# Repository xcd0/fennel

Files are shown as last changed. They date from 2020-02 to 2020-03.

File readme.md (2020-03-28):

# fennel

fan90のPCB、アクリルケースの発注が終わった。暇。この間に次のキーボードを作る。  
とりあえず名前はそのまま引き継ぐ。古いものは別ブランチに残す。別リポジトリにするかも...

## コンセプト

両手用左右分離型キーボード。fan90を小さくした。 片手に37キーの予定。  
ただしキーマトリクスが余る分を小さなリセットスイッチなどで設け、  
あまり使用頻度が高くない機能を割り当てる(マイコンの設定など)。  

* 指に合わせていい感じにキーが配置されてる両手で使えるキーボード欲しい。fan90二つはちょっと...
* fan90は流行に逆らったマキシマムな設計だったので、次は長いものに巻かれる小さ目な設計にする。
* 基盤はfan90と同じように両面対応する。
* fan90では筋力的にできなかった左右分割のキーボードにする。（左右間で通信する）
* ~~ケースはできれば3Dプリンターを使ってみる。~~ 基盤でケース作る方向にした。
* fan90のねじ数が少なくてちょっとたわむのでねじを増やす。
* Pro MicroではなくBluePillを使ってみる。

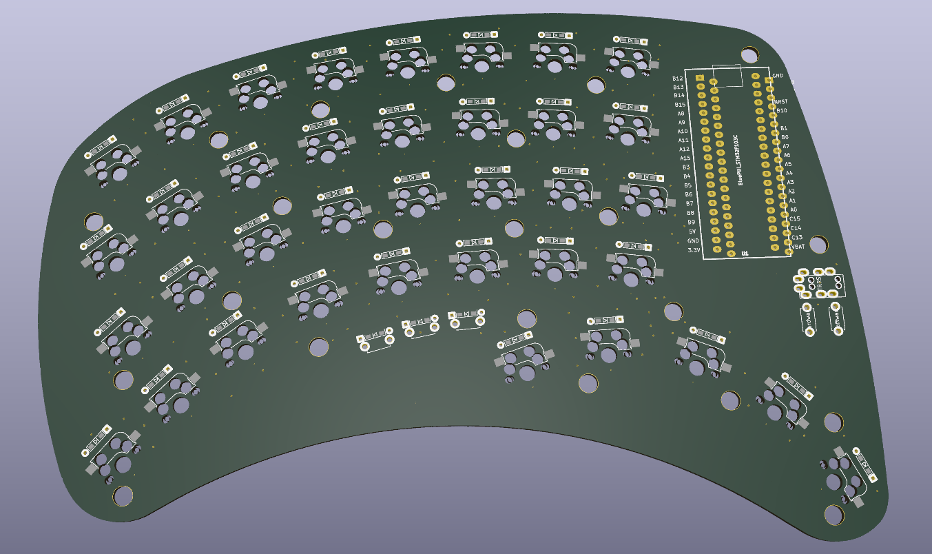
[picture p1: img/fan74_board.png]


外形が難しい... \_(:3 」∠ )\_

## 設計

fan90に比べ、
* 左右分離(通信)
* BluePillを使う(ARM)
の2点により難易度が上昇している。
というか参考にできる情報がすくない。

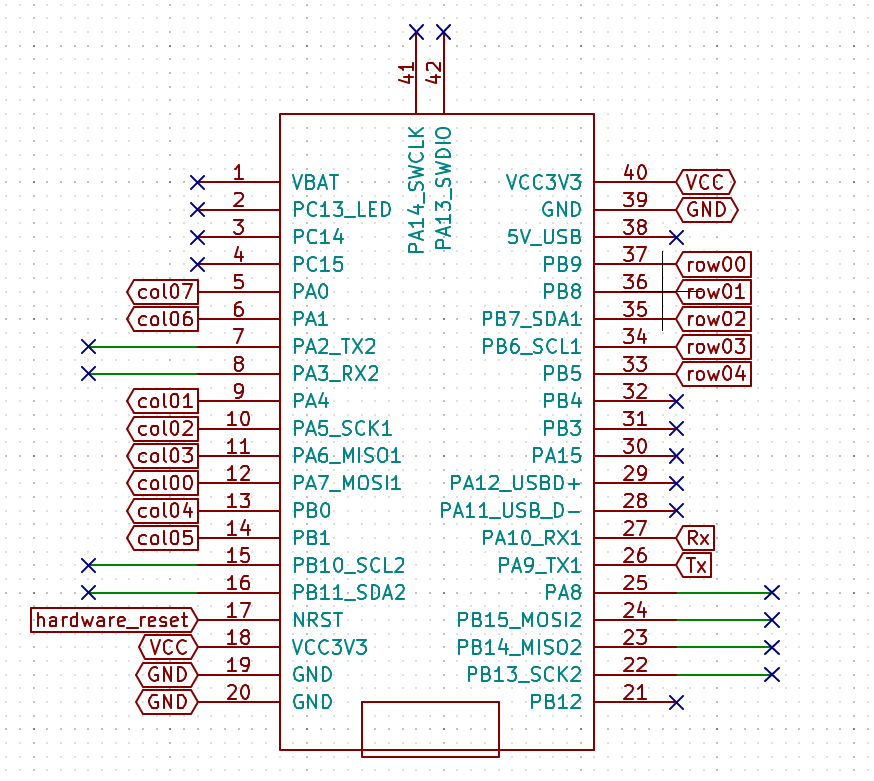
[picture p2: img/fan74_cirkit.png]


現状回路がよくなさそうなので長い目で決めていく。

* UART半二重通信をする予定
	* [](https://kondo-robot.com/faq/serial-servo-method-tech)
	* 右手のbluepillはスキャンしてひたすら左手に送信するだけ
	* 左手は受け取って左手のスキャン情報と合わせてPCにUSB経由で送信
	* 通信用の信号線(回路図のdata)はpullupしつつ、GNDとツェナーダイオードでつなぐ。
* pullup抵抗を入れる
	* 10kΩが多いみたい。
	* 1.5kΩの抵抗が余ってるからこれでもいいかな...
	* wikipediaによるとバイポーラは1kΩ～4.7kΩ、CMOSでは220kΩ～1MΩらしい
	* データシートにweak pull-up equivalent resistorの記述があるので、  
	内蔵のプルアップ抵抗も使えるみたい。VINとVSSをつなぐと30～50kΩになるみたい。(43ページ)
* RX は入力端子なので保護抵抗を入れる。
	* これも1.5kΩでいいかな...
	* データシートにたしかに10kΩ書いてあるので10kΩにした方がよさそう
* 使ってないIOピンもVCCかGNDに10kΩ挟んでつなぐ
	* どっちでもいいみたい
	* これは外部でプルアップ/ダウンする必要があるみたい
	> All unused pins must be held at a fixed voltage, by using the I/O output mode, an external pull-up or pull-down resistor
* キーマトリクスに割り当てるピン配置を変える

* 異種面付けをしてみた
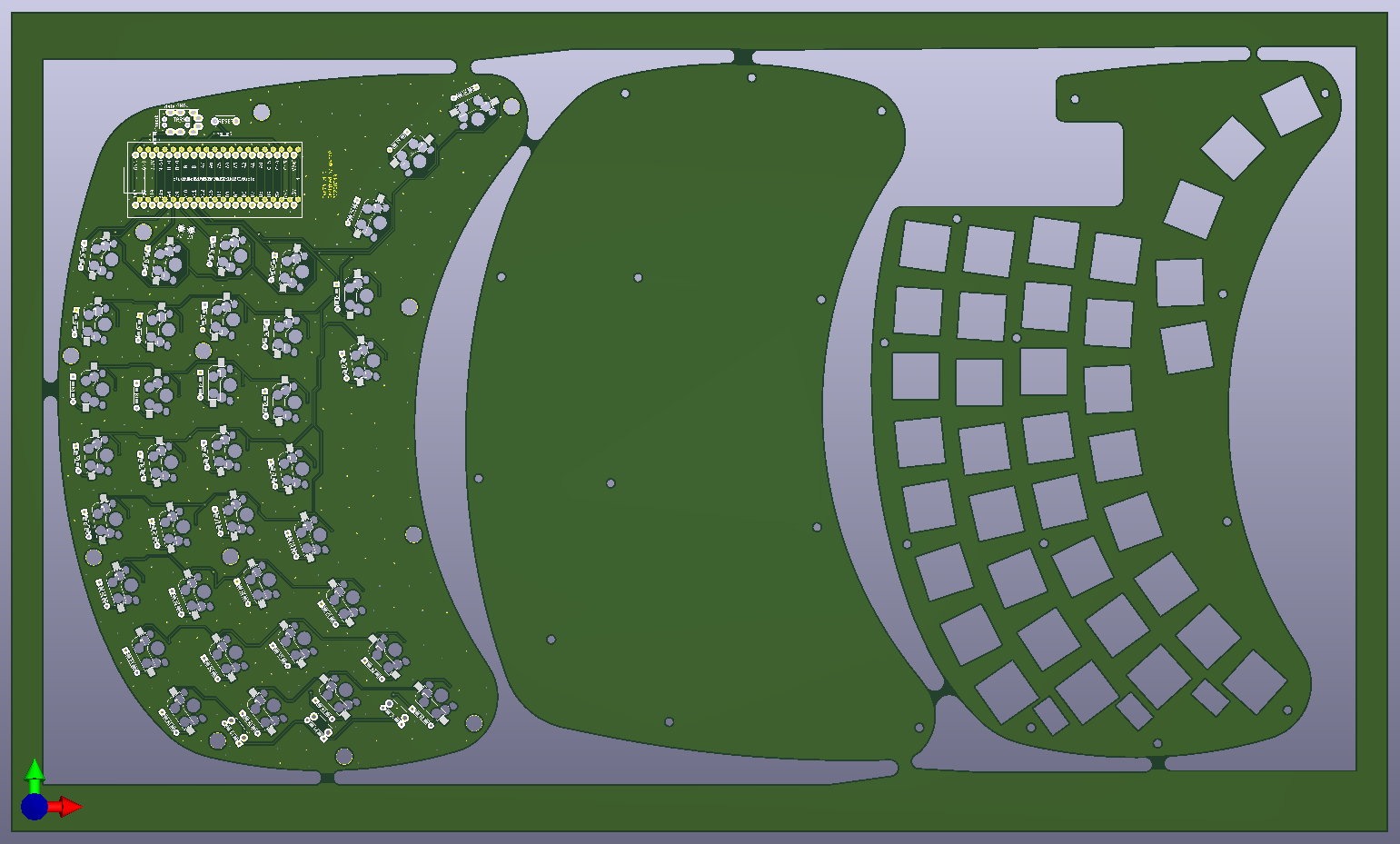
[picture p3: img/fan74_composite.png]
	
	* お値段 5枚製造
		* 異種面付けで基板製造の費用$93
		* 異種面付けしないで３枚頼んだ時の基板製造費$33
	* かすかに安いが、後加工が必要になるので、その点で普通に注文したほうよい。

### STM32F103について

調べて分かったことのメモ。間違っているかも。

* 内部回路の電源が分かれている。
	* VBAT はRTCとか用
		* ボタン電池とかをつないでRTCを維持できるみたい。
	* 1.8Vはコア回路用
	* VDDはデジタル回路用
	* VDDAはアナログ回路用

* リセットは3種類ある
	1. 電源を切る
	1. NRSTをGNDにつなぐ
	1. backup領域のみリセットする(そもそもbackup領域とは..)
		* BDRSTレジスタでリセット
		* VDDがONでリセット
		* VBATがONでリセット

* ピンについて
	* PA9がTx、PA10がRx。
	* PA15、PB3、PB4はJRAGデバッグに使われている(JTAGデバッグとは...)ので使おうとするとひと手間いる。
	* PB2はジャンパにつながっている。
	* PA11、PA12はUSB端子につながっている。
	* generic bootloader向け
		* bootloaderの種類はbluepillの実装に合わせる。generic_boot20_xxx.binのxxxはLEDのpinに合わせる。
			* 合わせることでDFUモードの状態をLEDで表示できる。
		* PA12はUSBリセットに使われているので、外部HWをつながない方がよい。
		* PC13はDFUの状態をLEDで表示するのに使われているので、外部HWをつながない方がよい。
		* PC14はNRSTに使われているので、外部HWをつながない方がよい。
			* PC14を3.3VにプルアップするとDFU永続モードになる？
			* DFU永続モードにできるなら有用なので専用回路を実装したい。
			* PC14をhigh→リセット→書き込み→PC14を開放→リセットの流れっぽい。

* 書き込みについて
	* USB経由での書き込みはタイミングよくリセットボタンを押す必要があるらしい。
		* 「Arduinoの書き込みを押した後0.5秒後くらいにボードのリセットを押す」らしい...

## リンク集

* 一番詳しかった  
ＤＥＫＯのアヤシいお部屋。 - STM32F103 https://ht-deko.com/arduino/stm32f103c8t6.html

* DFUモードの0.5秒の情報はここ  
adfmac/bluepill-arduino.md https://gist.github.com/tadfmac/f1dffc8c674ddaa8bd2340a8ddec65be

## ケース

基板と一緒に頼んだ。

## 回路間違っていた。
頼んだタイミングが残業で疲れた深夜だったため、いろいろミスった状態で発注した\_(:3 」∠ )\_
労働は体に良くない。

とりあえずゴリゴリ基盤を削って空中配線してごまかした。

## ファームウェア

[Ortho 75](https://github.com/qmk/qmk_firmware/tree/master/keyboards/cannonkeys/ortho75)を参考にする。

とりあえずこぴっていじる

<!--{{{-->

## 以下古いバージョン

<details>
<summary>v1 fan90 片手用フルキーボード</summary>

## one hand keyboard fan90

片手用キーボードです。G13のような用途を想定しています。  
左手で使うことを想定していますが、右手でも使えるようにPCBは作っています。  
流行りのミニマムなキーボードとは反対方向のマキシマムな方向のキーボードです。  
両手で使うことを想定していませんが、両面対応しているので2つ用意すれば可能です。  

初めての自作キーボードなので楽しみなのと不安なのが混在しています\_(:3 」∠ )\_
あくまで初めてつくる自作キーボードであるため、当然ながら動かない可能性が高いです。

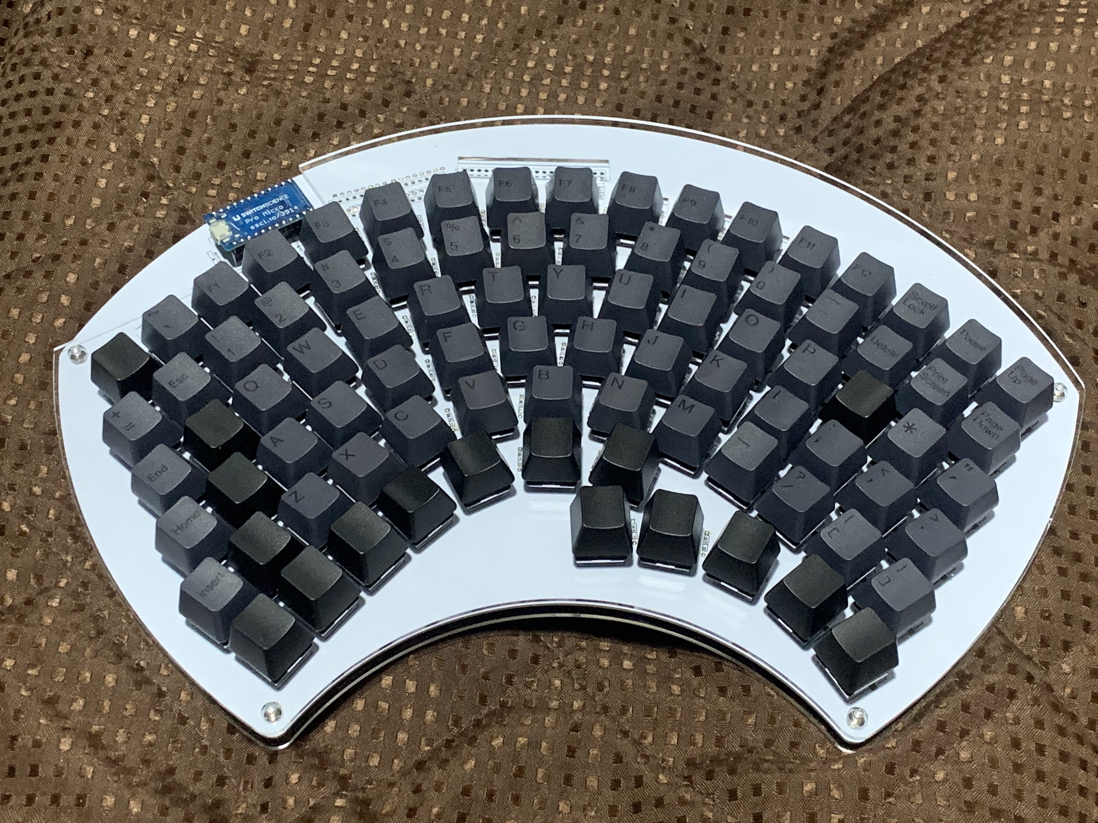
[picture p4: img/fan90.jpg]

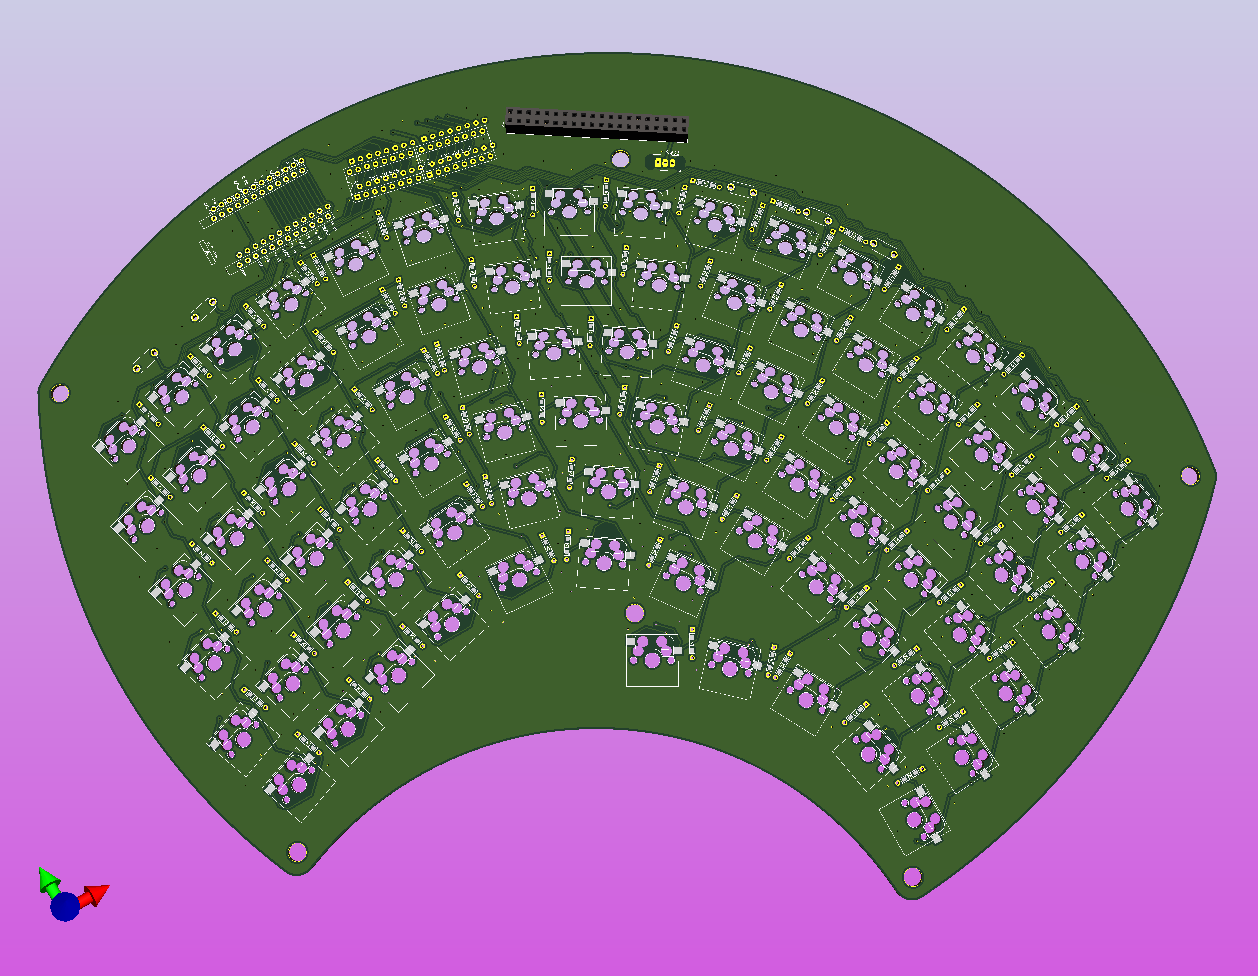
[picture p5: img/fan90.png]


<details>
<summary>開発経緯</summary>

### キーボード割ろうとしたら曲がった
* ありものは素晴らしい、でも自分で作ってみたい。よし、初めてのキーボード自作だ！PCBから作るぞ\\('ω')/
* 今使ってるhelixよい。でもErgodox的な縦のずれがあるキーボードもよさそう。そういうの作ろう...
* 左右分割型のキーボード良い。割りたい！でも左右の通信とかどうやってるんだろう...ちゃんと作れるかな...
* とりあえずキーを並べてみる。小指とか根元に近く配置しよう...
* 見た目汚いな...とりあえずきれいに並べてみるか...あれ、なんか曲がってきた...
* あれこれ片手でフルキーボードいけるんじゃ...

という感じでした\_(:3 」∠ )\_  
つまりキーボードを割ろうとしたが、  
筋力が足りなかったため（左右に分割したときの左右間の通信を電源(VCC,GND)と信号線の3本でどうやって通信してるのかわからなかったので）、  
割れずに曲がってしまった。  
次作るときは割りたい。  
名前は見た目がうちわのようになったため。  もちろん余った基板は重めの団扇として使うことができる。
鍋敷きにしてもよい。
</details>

<details>
<summary>構想</summary>

#### コンセプト
以下で東西南北を言うときは、左手で中指の方向を北とした場合の手のひらからの方向を指します。

* 片手でたくさんのキーを使える。
	* フルキーボード相当のキーを使えるものとする。
		* 現状6x15のマトリクスで87キーを配置。
		* 残り３キーはあまり使わない用途向けにリセットスイッチ部品で配置。

* 片手で使いやすい。
	* 指毎の特徴に合わせて配置する。  
		例えば
		* 親指はゲームのコントローラーで多用されるように本来非常に性能が良い。  
		しかしキーボードを使う上で親指を生かすのは難しい。  
		Twitterの投票によると親指に複数のキーを割り当てているときに使っているキーの数はせいぜい4キーらしい。  
		このキーボードでは多めに5キーを割り当てる。
		* 人差し指は性能が良くQWERTYでもほかの指より多いキーを担当する。  
		このキーボードでも人差し指の担当は多くする。
		* 中指は人差し指と同じくらいのせいのがある。中指にも多めのキーを割り当てる。
		* 薬指は中指と一緒に動かないと性能が良くないので、キーボードではあまり性能を発揮できない。
		ただし、北西方向は強く、北西方向に関しては小指より適している。。
		* 小指は短いので、北西方向の移動は難しい。  
		しかし西方向、南西方向はそこそこ性能が良い。
	* 指に合わせてキーを配置する。
		* 変則的な配置なので指１本に対して割り当てられたキーの数は様々。
			* 現状小指20、薬指15、中指12、人差し指31、親指5キー。人差し指と小指は無駄キーを含む。足しても90にはならない。
		* 将来的にはキーを立体的に配置するのもよいが、現状は平面に配置。
	* 指は伸ばした状態のほうが押しやすく、キーを押し分けやすい。
		* 指の根本に近いキーよりも指を伸ばしたときに押すキーのほうが押しやすい。
		* 指の根元に近いキーを減らし、指を伸ばしたときに押すキーを増やす。
	* レイヤーは極力つかわない。
		* シフトキーのように押しながら操作することは片手だと難しい。

* すべてのキーを常に使うキーにはせず、使う用途に合わせてカスタマイズできるよう、無駄にキーを配置する。

#### 実現方法

* 以下の2点からキーを扇状に配置する。
	* 小指の性能を発揮できるように小指のキーは手首側に寄せる。
	* 伸ばした状態で使える人差し指、中指のキーを増やす。
* 列方向には揃えず、行方向にはそろえる。
* 無駄にキーを小指の西側、人差し指の東側、すべての指の北側に配置する。つまり一回り大きくする。

#### 将来的にやりたいこと

* QMKを使わずに作る。(現状使う)
* C以外の言語で作る。(現状C言語)
* マイコンを複数種類使えるようにする。(現状むずかしい)
* raspberry pi zeroと画面を搭載して、それ単体でPCとして動作させ多機能にする。(現状ソケットのみ用意)
* ケースを3Dプリンターなどでつくる。
* キーを立体的に配置する。

</details>

### PCB設計

kicadを使って設計した。

回路は6x15のマトリクス。column方向からスキャンし、rowを検出する。  
column方向のスキャンは床に転がっていたSN74HC595を使う。  
シフトレジスタを使えば簡単にスキャンできそう。  
これで信号線数を15-5で10本減らせることになる。  
pro microはデジタルIOピンが14本、デジタルとしても使えるアナログIOピンが4本なので、
最大18本をデジタルIOとして使うことができる。
6本をrowのデジタル入力に、5本をシフトレジスタへのデジタル出力に、
2本をリセットスイッチに使用することにした。
配置は特にこだわりなく並べた。このせいで後々苦労するかもしれないがまあ初めてなので良しとする。

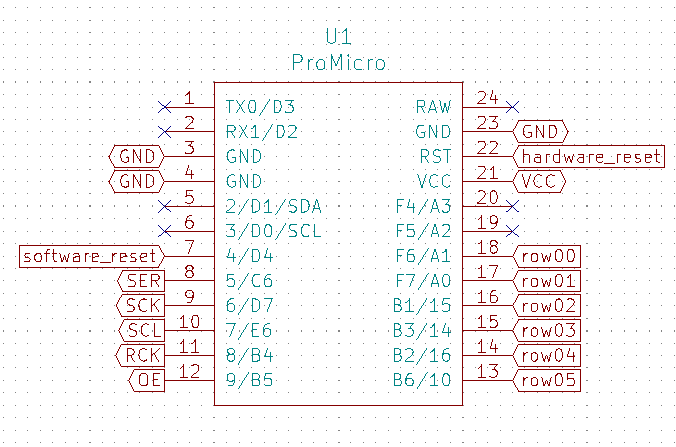
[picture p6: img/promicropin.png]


### アクリルケース設計

* ケースもとりあえずアクリルで作ることにした。
* ケースもDXFで入稿できるみたいなのでkicadでそのまま作った。
	* SVGでもよさそうだがそもそもSVGで線幅を狭くするとinkscapeやchromeで表示したとき線が描画されない問題があった。
* アクリルは[工房Emerge+](https://www.emergeplus.jp/laser-cutting-service/)を使ってみることにした。
	* elecrowはウェブサイトの調子が良くないのか、そもそもサービス中止中なのか、  
	https://twitter.com/xcd0/status/1233658167684296704  
	のようにfalseとなっていた。
	* 遊舎工房は、キーボードのサイズが大きいので元のアクリル板が最低でもA3より大きな必要があり、  
	A5,A4,450 X 300と、450x300以外の選択肢がなく、このサイズでも2枚発注する必要がある。  
	そして150x300程度の余白ができてしまう。
	* Emarge+は600x300に対応しており、これだと１枚に収まる。なのでここにしてみた。
	* 遊舎工房とEmerge+はillustratorありきの体制で、すごくストレスフルであった。
	* inkscapeは線幅の問題で使えず、外形と内形を色を変えるとかレイヤーを変えるとか言った操作はillustratorがないと難しいというか不可能な作業であった。
	* 今回５個ほどソフトを試したが、どれも満たせずあきらめてillustratorの7日間仕様版を使った。
	* 次回はaiやsvgではなくDXFで入稿したい。
	* elecrow復活してほしい...
* データ蹴られるかと思ったがとりあえず通った。
* DXFもレイヤー分けていればよいらしい。

### プログラム作成

qmkでもよいがとりあえず動作確認にarduinoを使う。
以下を参考にarduino studioで書き込めるか調べる。
https://learn.sparkfun.com/tutorials/pro-micro--fio-v3-hookup-guide#installing-windows
https://learn.sparkfun.com/tutorials/pro-micro--fio-v3-hookup-guide/hardware-overview-pro-micro



</details>
<!--}}}-->

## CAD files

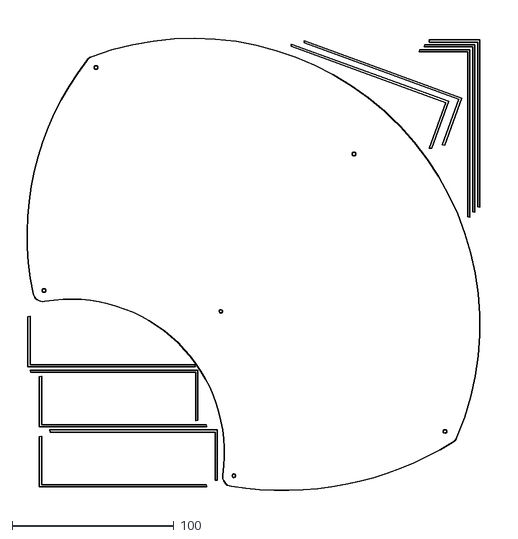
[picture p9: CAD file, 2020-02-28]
fan/fan_case/fan_case-Eco2_User.dxf
300.2 x 298.2

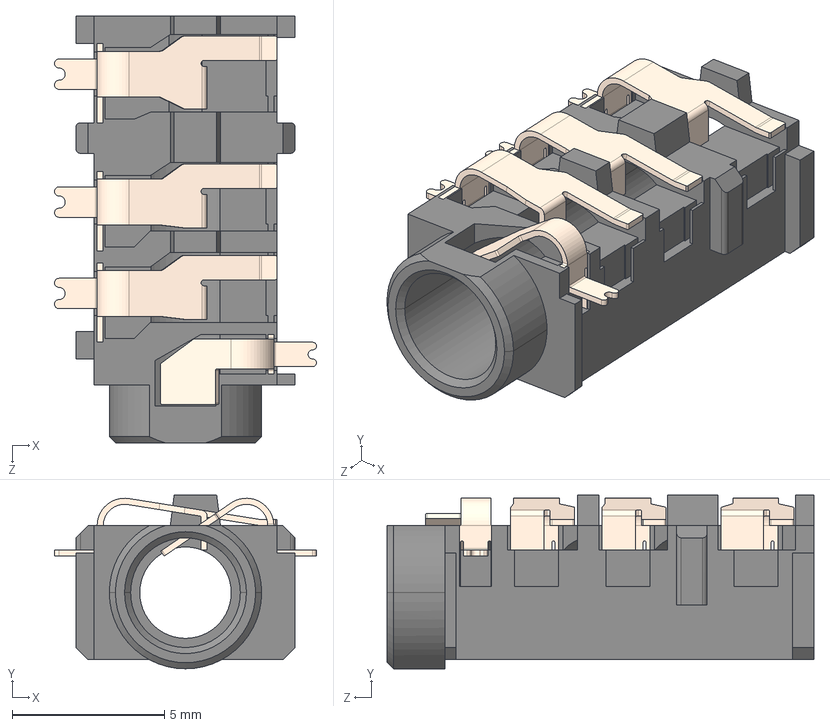
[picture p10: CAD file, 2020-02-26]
kbd/Keebio-Parts.pretty-master/3dmodels/CUI_SJ-43614-SMT-TR.step
8.60 x 5.70 x 14.0 mm

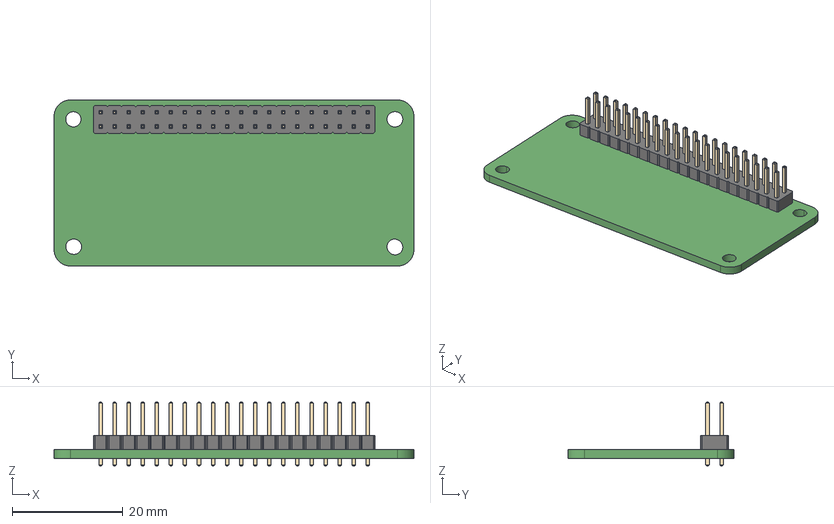
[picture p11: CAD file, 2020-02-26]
kbd/KiCad-Templates-master/3D Models/Raspberry Pi Zero W.step
65.0 x 30.0 x 11.5 mm

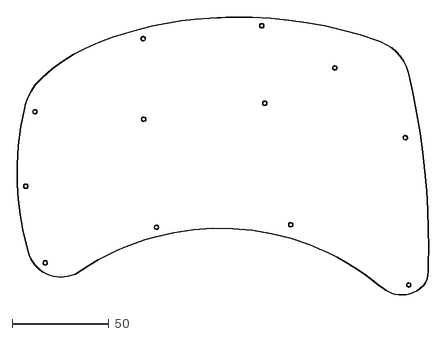
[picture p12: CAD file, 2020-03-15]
pcb/gbr/fan-Eco2_User.dxf
213.3 x 144.8

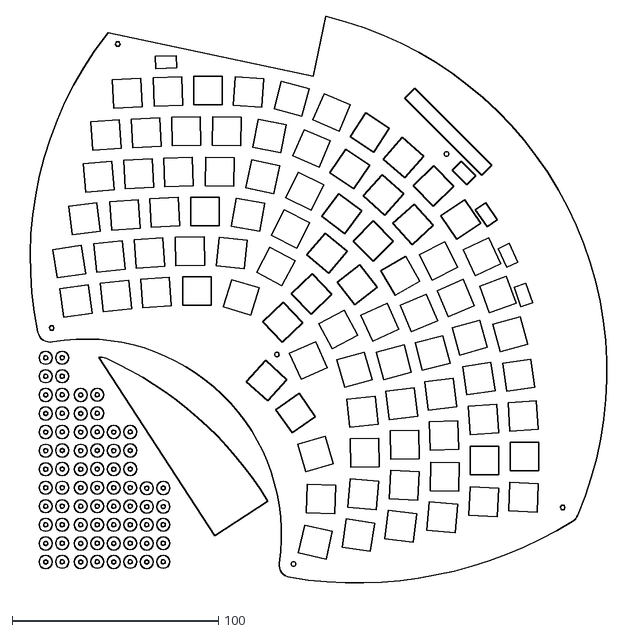
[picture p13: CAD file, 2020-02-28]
fan/fan_case/fan_case-Eco1_User.dxf
292.9 x 279.8

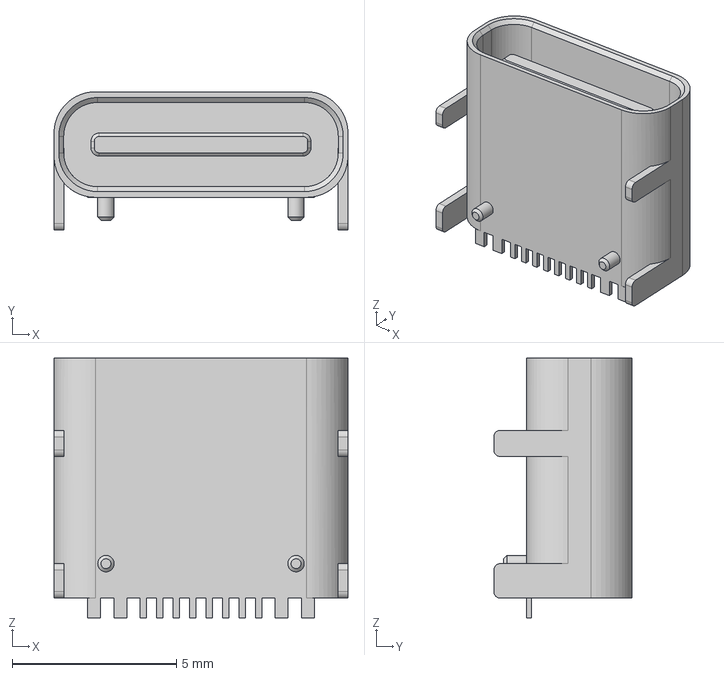
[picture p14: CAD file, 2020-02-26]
kbd/Keebio-Parts.pretty-master/3dmodels/HRO TYPE-C-31-M-12.step
8.94 x 4.21 x 7.90 mm

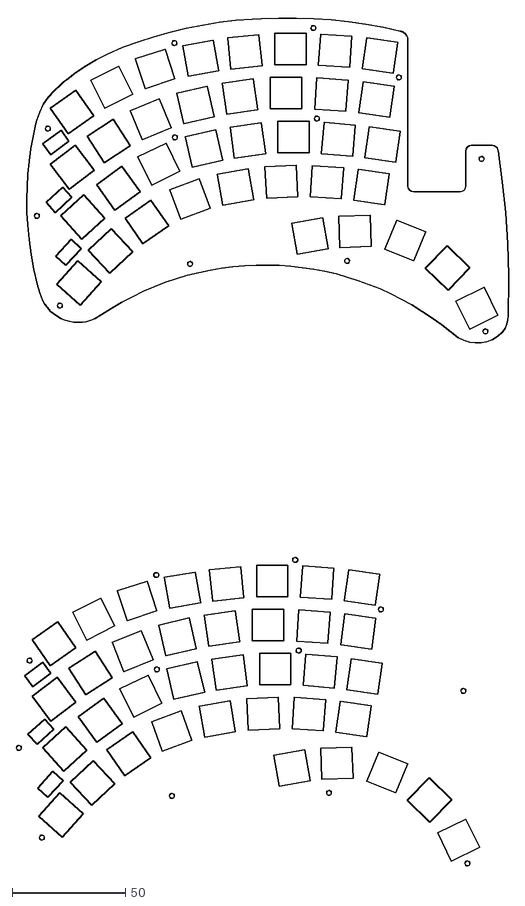
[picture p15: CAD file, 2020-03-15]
pcb/gbr/fan-Eco1_User.dxf
217.5 x 375.4

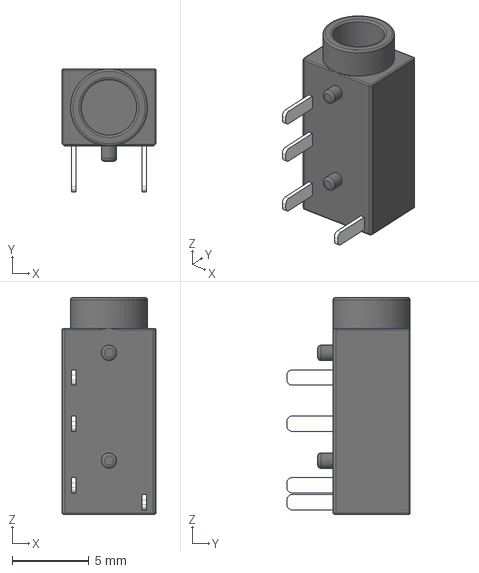
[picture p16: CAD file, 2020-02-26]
kbd/Keebio-Parts.pretty-master/3dmodels/PJ-320A.step
6.10 x 8.00 x 14.1 mm

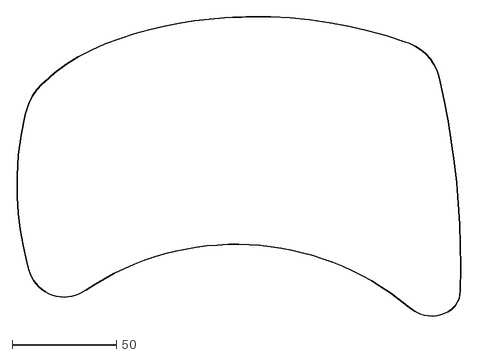
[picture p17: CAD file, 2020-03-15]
pcb/gbr/fan-Edge_Cuts.dxf
213.3 x 144.8

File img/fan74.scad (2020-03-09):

translate([0, 0, 4]) 
linear_extrude(height=1.6){
  offset(0){
    union(){
import("./pcb/gbr/fan-Edge_Cuts.dxf", $fa=1);
    }
  }
};
translate([0, 0, 0]) 
linear_extrude(height=2){
  offset(1){
    union(){
import("./pcb/gbr/fan-Edge_Cuts.dxf", $fa=1);
    }
  }
};

translate([0, 0, 5.6]) 
linear_extrude(height=2){
    
  difference(){
  offset(3){
import("./pcb/gbr/fan-Edge_Cuts.dxf", $fa=1);
}
import("./pcb/gbr/fan-Eco1_User.dxf", $fa=1);
  }
};

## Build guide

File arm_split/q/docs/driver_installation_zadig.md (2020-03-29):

# Bootloader Driver Installation with Zadig

QMK presents itself to the host as a regular HID keyboard device, and as such requires no special drivers. However, in order to flash your keyboard on Windows, the bootloader device that appears when you reset the board often *does*.

There are two notable exceptions: the Caterina bootloader, usually seen on Pro Micros, and the HalfKay bootloader shipped with PJRC Teensys, appear as a serial port and a generic HID device respectively, and so do not require a driver.

We recommend the use of the [Zadig](https://zadig.akeo.ie/) utility. If you have set up the development environment with MSYS2 or WSL, the `qmk_install.sh` script will have asked if you want it to install the drivers for you.

## Installation

Put your keyboard into bootloader mode, either by hitting the `RESET` keycode (which may be on a different layer), or by pressing the reset switch that's usually located on the underside of the board. If your keyboard has neither, try holding Escape or Space+`B` as you plug it in (see the [Bootmagic](feature_bootmagic.md) docs for more details). Some boards use [Command](feature_command.md) instead of Bootmagic; in this case, you can enter bootloader mode by hitting Left Shift+Right Shift+`B` or Left Shift+Right Shift+Escape at any point while the keyboard is plugged in.
Some keyboards may have specific instructions for entering the bootloader. For example, the [Bootmagic Lite](feature_bootmagic.md#bootmagic-lite) key (default: Escape) might be on a different key, e.g. Left Control; or the magic combination for Command (default: Left Shift+Right Shift) might require you to hold something else, e.g. Left Control+Right Control. Refer to the board's README file if you are unsure.

To put a device in bootloader mode with USBaspLoader, tap the `RESET` button while holding down the `BOOT` button.
Alternatively, hold `BOOT` while inserting the USB cable.

Zadig will automatically detect the bootloader device. You may sometimes need to check **Options → List All Devices**.

 - For keyboards with Atmel AVR MCUs, the bootloader will be named something similar to `ATm32U4DFU`, and have a Vendor ID of `03EB`.
 - USBasp bootloaders will appear as `USBasp`, with a VID/PID of `16C0:05DC`.
 - AVR keyboards flashed with the QMK-DFU bootloader will be named `<keyboard name> Bootloader` and will also have the VID `03EB`.
 - For most ARM keyboards, it will be called `STM32 BOOTLOADER`, and have a VID/PID of `0483:DF11`.

!> If Zadig lists one or more devices with the `HidUsb` driver, your keyboard is probably not in bootloader mode. The arrow will be colored orange and you will be asked to confirm modifying a system driver. **Do not** proceed if this is the case!

If the arrow appears green, select the driver, and click **Install Driver**. The `libusb-win32` driver will usually work for AVR, and `WinUSB` for ARM, but if you still cannot flash the board, try installing a different driver from the list. For flashing a USBaspLoader device via command line with msys2, the `libusbk` driver is recommended, otherwise `libusb-win32` will work fine if you are using QMK Toolbox for flashing.

Zadig with a bootloader driver correctly installed

Finally, unplug and replug the keyboard to make sure the new driver has been loaded. If you are using the QMK Toolbox to flash, exit and restart it too, as it can sometimes fail to recognize the driver change.

## Recovering from Installation to Wrong Device

If you find that you can no longer type with the keyboard, you may have accidentally replaced the driver for the keyboard itself instead of for the bootloader. This can happen when the keyboard is not in the bootloader mode. You can easily confirm this in Zadig - a healthy keyboard has the `HidUsb` driver installed on all of its interfaces:

A healthy keyboard as seen by Zadig

Open the Device Manager and look for a device that looks like your keyboard.

The board with the wrong driver installed, in Device Manager

Right-click it and hit **Uninstall device**. Make sure to tick **Delete the driver software for this device** first.

The Device Uninstall dialog, with the "delete driver" checkbox ticked

Click **Action → Scan for hardware changes**. At this point, you should be able to type again. Double check in Zadig that the keyboard device(s) are using the `HidUsb` driver. If so, you're all done, and your board should be functional again!

?> A full reboot of your computer may sometimes be necessary at this point, to get Windows to pick up the new driver.

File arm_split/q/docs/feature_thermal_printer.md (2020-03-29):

# Thermal Printer

<!-- FIXME: Describe thermal printers support here. -->

## Thermal Printer Keycodes

|Key |Description |
|---|---|
|`PRINT_ON` |Start printing everything the user types|
|`PRINT_OFF`|Stop printing everything the user types |

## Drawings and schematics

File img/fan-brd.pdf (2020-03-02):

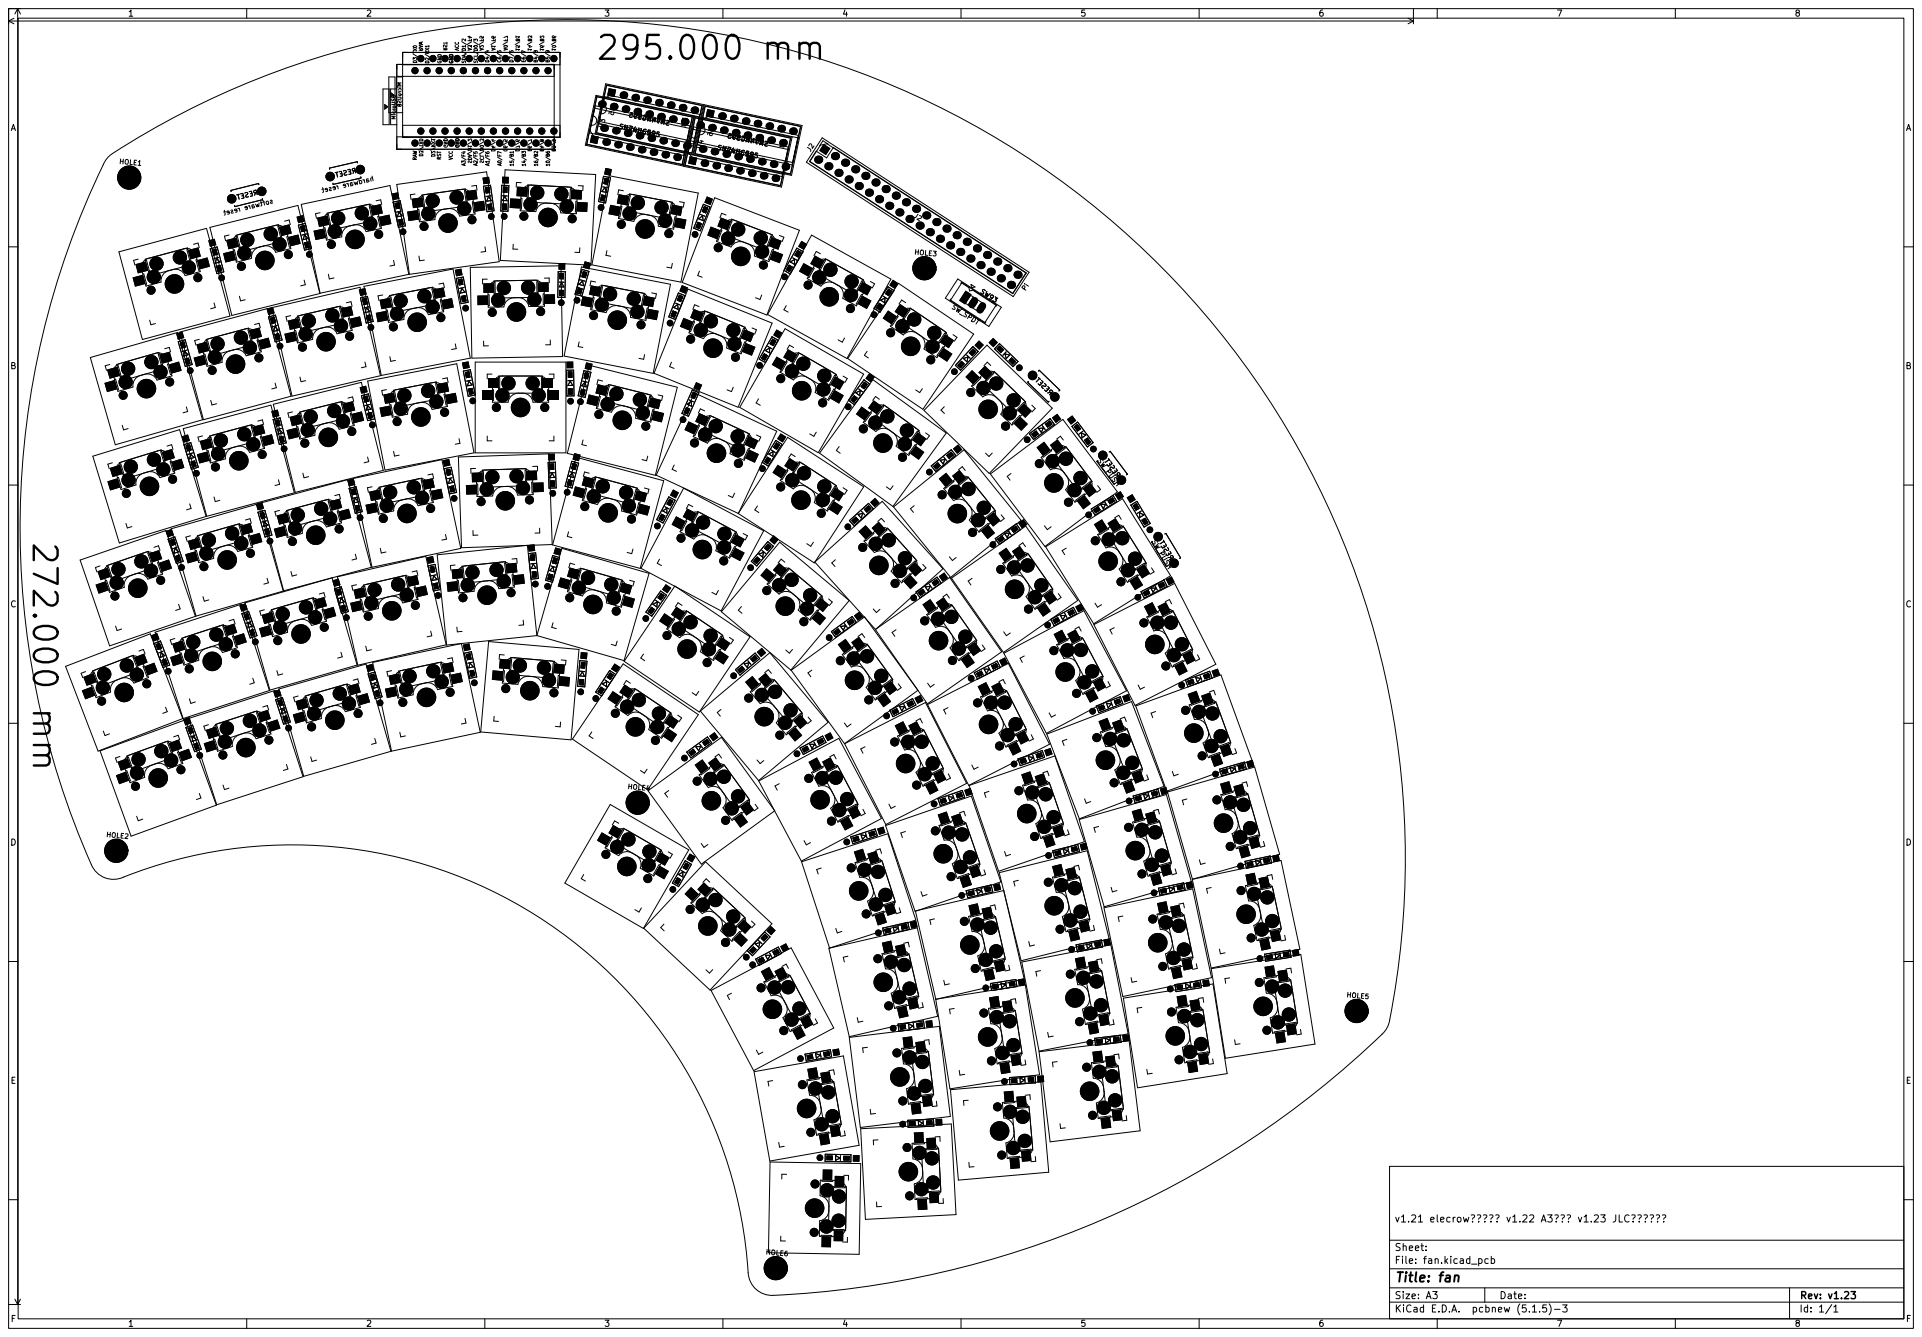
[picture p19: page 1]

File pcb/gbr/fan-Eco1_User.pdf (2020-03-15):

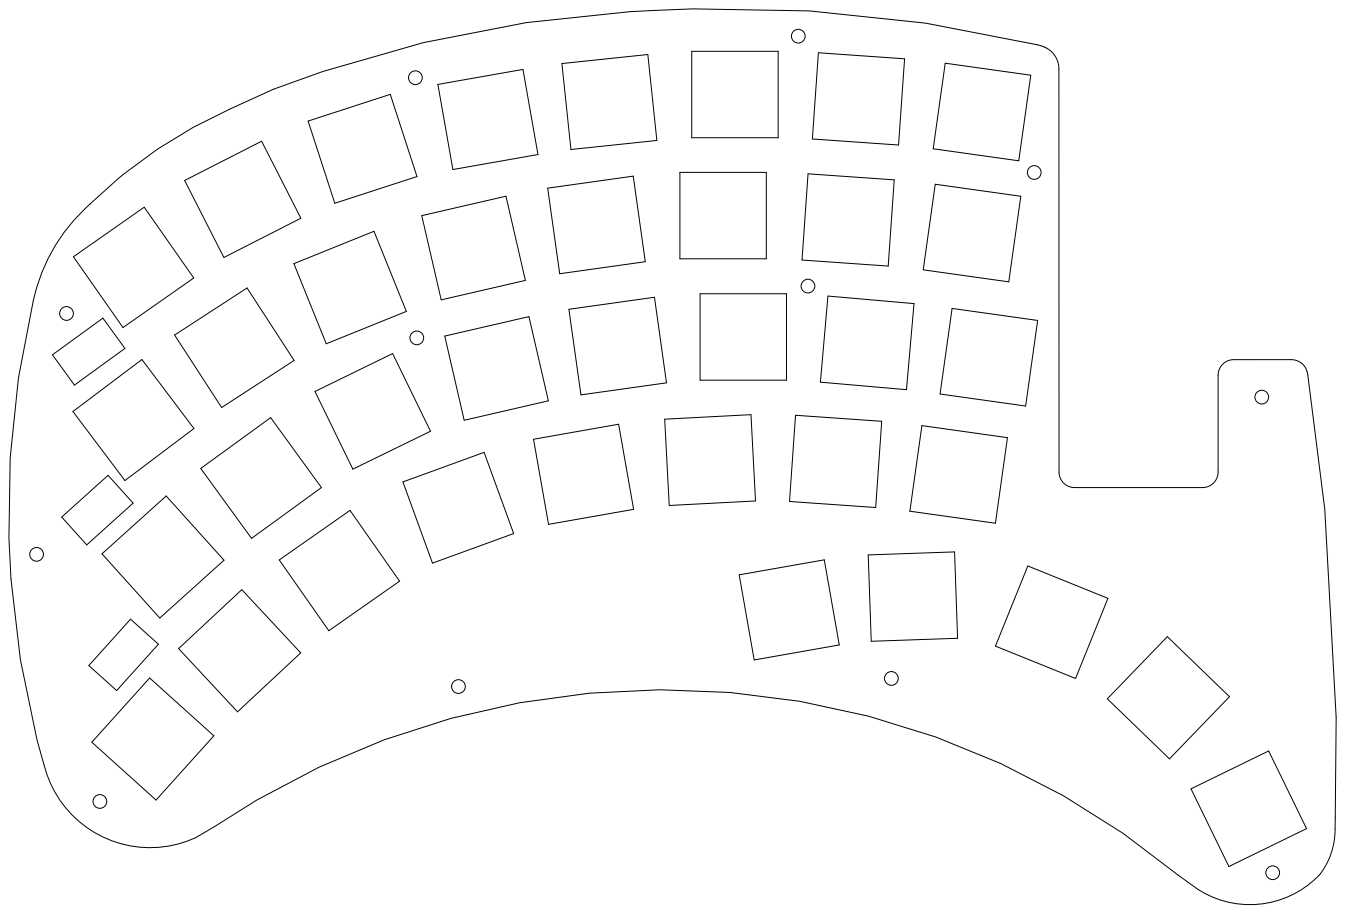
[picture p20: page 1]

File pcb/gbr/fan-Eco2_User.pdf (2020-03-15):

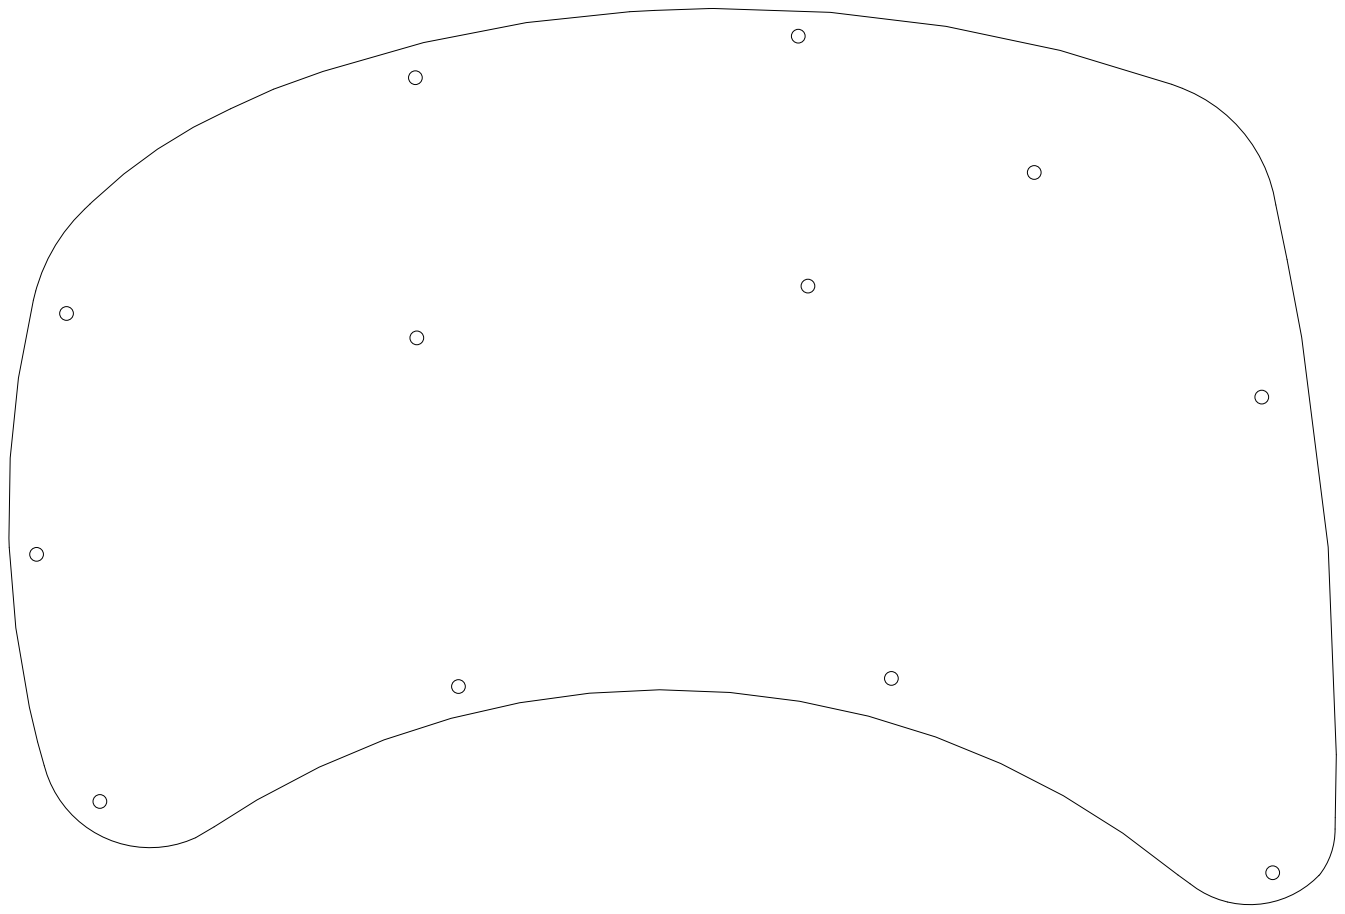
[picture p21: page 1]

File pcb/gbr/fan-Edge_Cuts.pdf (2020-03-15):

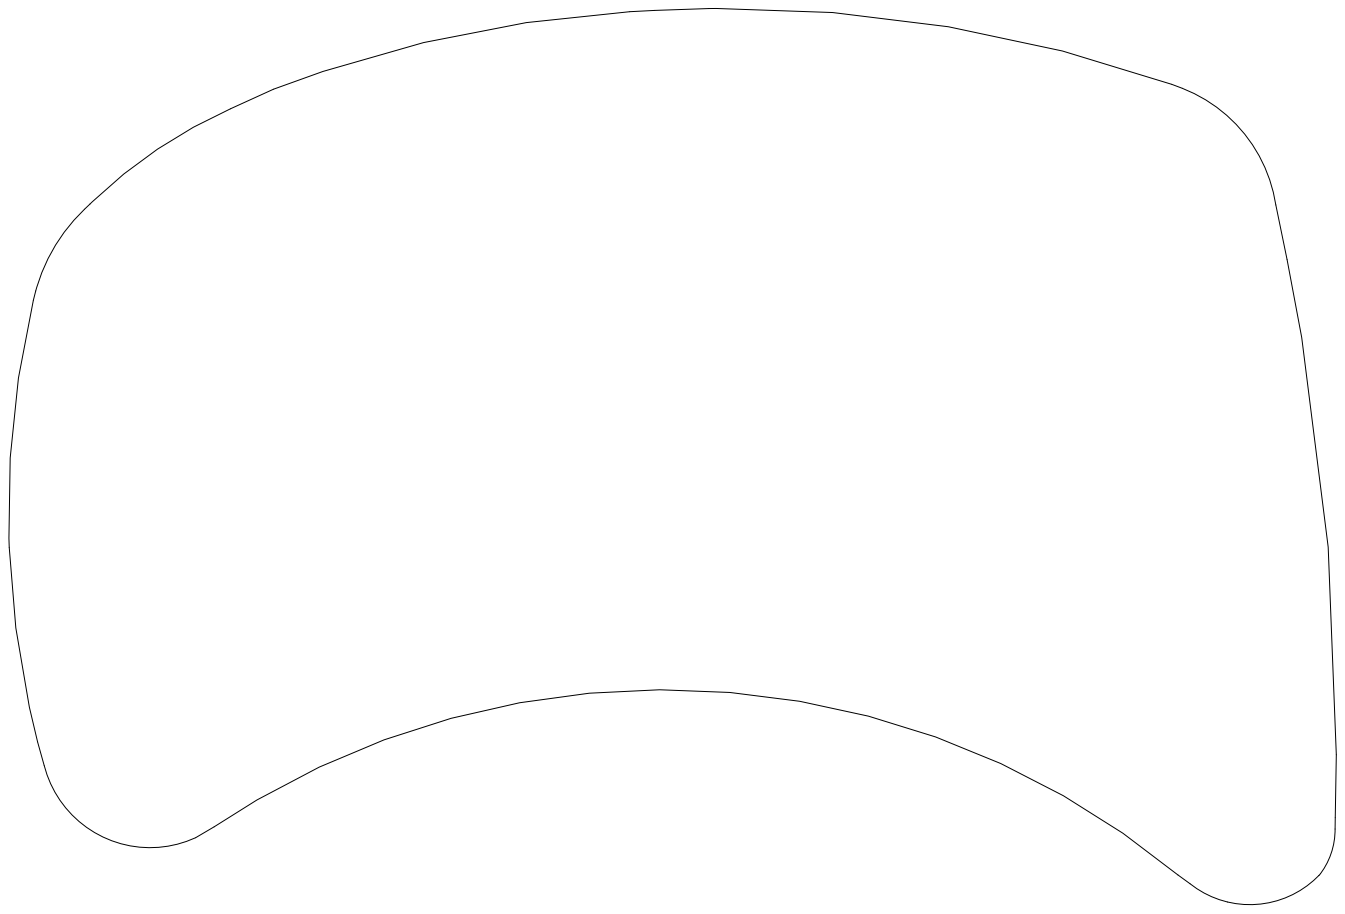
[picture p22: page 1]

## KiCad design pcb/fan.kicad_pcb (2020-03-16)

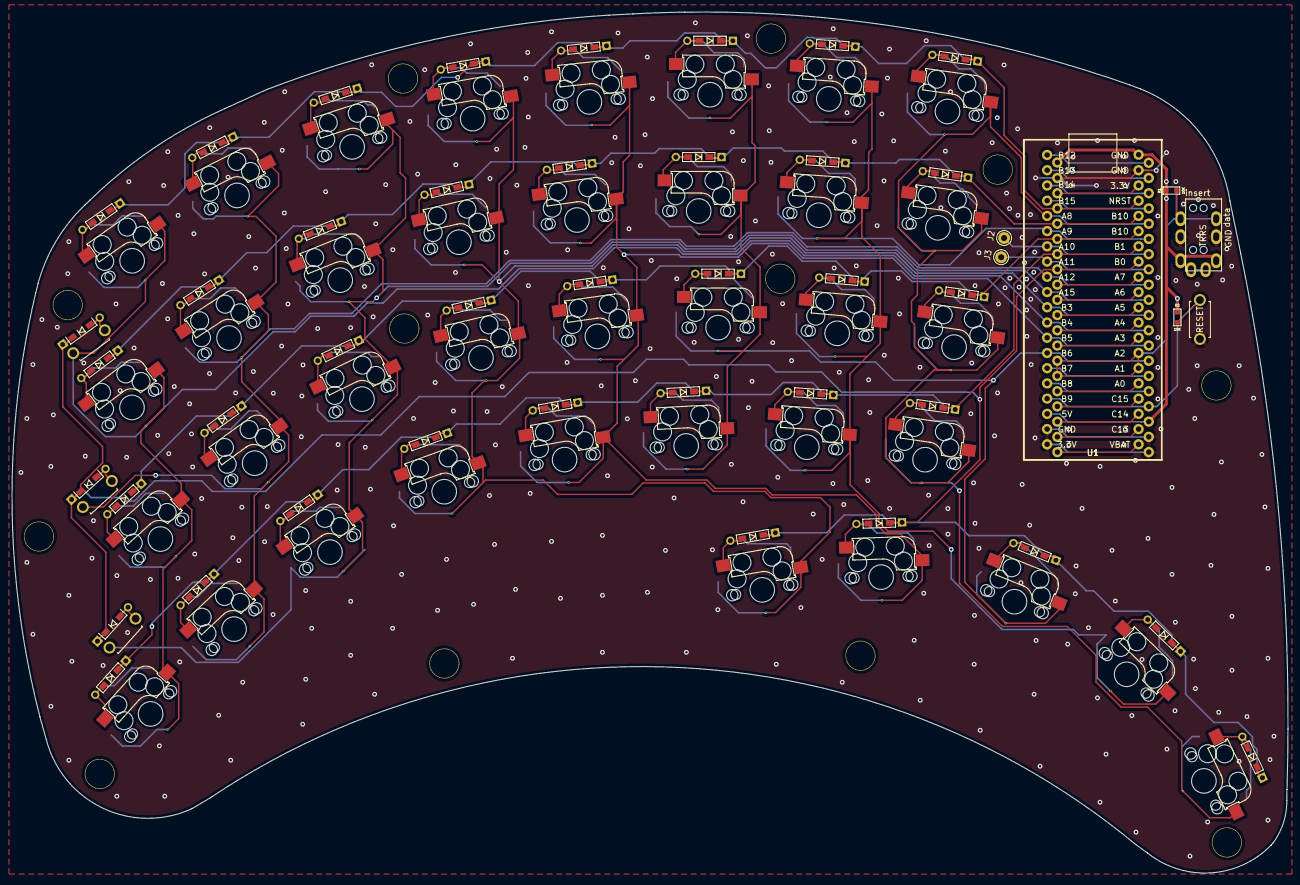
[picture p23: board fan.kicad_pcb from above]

Board: 2 copper layers, 212.8 x 143.6 mm, 59 parts (0 on the bottom side), 19 nets.

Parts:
J1: MJ-4PP-9
J2, J3: Conn_01x01_Female; Pin_D1.0mm_L10.0mm
R1, R2: 10K; R_1608_rev2
Ref**: Val**; HOLE
Ref**#2, Ref**#3, Ref**#4, Ref**#5, Ref**#6, Ref**#7, Ref**#8, Ref**#9, Ref**#10, Ref**#11, Ref**#12: Val**; HOLE
SW1, SW2, SW3, SW4, SW6, SW7, SW8, SW9, SW11, SW12, SW13, SW14, SW16, SW17, SW18, SW19, SW20, SW21, SW22, SW23, SW24, SW25, SW26, SW27, SW28, SW29, SW30, SW31, SW32, SW33, SW34, SW35, SW36, SW37, SW38, SW39, SW40: SW_PUSH-kbd; CherryMX_MidHeight_Hotswap_edit
SW5, SW10, SW15: SW_PUSH-kbd; ResetSW_with_diode
SW41: SW_PUSH; ResetSW
U1: BluePill_STM32F103C; BluePill_STM32F103C_0.9_Double

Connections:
GND: J1.C, SW41.2, U1.19, U1.20, U1.39
unnamed: J2.1, U1.7
unnamed: J3.1, U1.8
Rx: J1.B, R1.2, U1.26, U1.27
VCC: J1.D, R1.1, R2.1, U1.18, U1.40
col00: SW1.1, SW2.1, SW3.1, SW4.1, SW5.1, U1.12
col01: SW6.1, SW7.1, SW8.1, SW9.1, SW10.1, U1.9
col02: SW11.1, SW12.1, SW13.1, SW14.1, SW15.1, U1.10
col03: SW16.1, SW17.1, SW18.1, SW19.1, SW20.1, U1.11
col04: SW21.1, SW22.1, SW23.1, SW24.1, SW25.1, U1.13
col05: SW26.1, SW27.1, SW28.1, SW29.1, SW30.1, U1.14
col06: SW31.1, SW32.1, SW33.1, SW34.1, SW35.1, U1.6
col07: SW36.1, SW37.1, SW38.1, SW39.1, SW40.1, U1.5
hardware_reset: R2.2, SW41.1, U1.17
row00: SW1.3, SW6.3, SW11.3, SW16.3, SW21.3, SW26.3, SW31.3, SW36.3, U1.37
row01: SW2.3, SW7.3, SW12.3, SW17.3, SW22.3, SW27.3, SW32.3, SW37.3, U1.36
row02: SW3.3, SW8.3, SW13.3, SW18.3, SW23.3, SW28.3, SW33.3, SW38.3, U1.35
row03: SW4.3, SW9.3, SW14.3, SW19.3, SW24.3, SW29.3, SW34.3, SW39.3, U1.34
row04: SW5.3, SW10.3, SW15.3, SW20.3, SW25.3, SW30.3, SW35.3, SW40.3, U1.33

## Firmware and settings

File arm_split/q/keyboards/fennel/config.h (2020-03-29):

/*
Copyright 2020 xcd0

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
You should have received a copy of the GNU General Public License
along with this program.  If not, see <http://www.gnu.org/licenses/>.
*/

#pragma once

//#include "config_common.h"

/* USB Device descriptor parameter */
#define VENDOR_ID 0xFEED
#define PRODUCT_ID 0x0000
#define DEVICE_VER 0x0001
#define MANUFACTURER xcd0
#define PRODUCT fennel
#define DESCRIPTION A custom keyboard

/* key matrix size */
#define MATRIX_ROWS 5
#define MATRIX_COLS 16 // 片手で8 両手で16

#define MATRIX_ROW_PINS { B9, B8, B7, B6, B5  }
#define MATRIX_COL_PINS { A7, A4, A5, A6, B0, B1, A1, A0 }
#define UNUSED_PINS { B10, B11, B13, B14, B15, A8 }

/* COL2ROW, ROW2COL*/
#define DIODE_DIRECTION COL2ROW
//#define DIODE_DIRECTION CUSTOM_MATRIX

/*
 * Split Keyboard specific options, make sure you have 'SPLIT_KEYBOARD = yes' in your rules.mk, and define SOFT_SERIAL_PIN.
 */
//#define SOFT_SERIAL_PIN D0  // or D1, D2, D3, E6

// #define BACKLIGHT_PIN B7
// #define BACKLIGHT_BREATHING
// #define BACKLIGHT_LEVELS 3

// #define RGB_DI_PIN E2
// #ifdef RGB_DI_PIN
//   #define RGBLED_NUM 16
//   #define RGBLIGHT_HUE_STEP 8
//   #define RGBLIGHT_SAT_STEP 8
//   #define RGBLIGHT_VAL_STEP 8
//   #define RGBLIGHT_LIMIT_VAL 255 /* The maximum brightness level */
//   #define RGBLIGHT_SLEEP  /* If defined, the RGB lighting will be switched off when the host goes to sleep */
// /*== all animations enable ==*/
//   #define RGBLIGHT_ANIMATIONS
// /*== or choose animations ==*/
//   #define RGBLIGHT_EFFECT_BREATHING
//   #define RGBLIGHT_EFFECT_RAINBOW_MOOD
//   #define RGBLIGHT_EFFECT_RAINBOW_SWIRL
//   #define RGBLIGHT_EFFECT_SNAKE
//   #define RGBLIGHT_EFFECT_KNIGHT
//   #define RGBLIGHT_EFFECT_CHRISTMAS
//   #define RGBLIGHT_EFFECT_STATIC_GRADIENT
//   #define RGBLIGHT_EFFECT_RGB_TEST
//   #define RGBLIGHT_EFFECT_ALTERNATING
// /*== customize breathing effect ==*/
//   /*==== (DEFAULT) use fixed table instead of exp() and sin() ====*/
//   #define RGBLIGHT_BREATHE_TABLE_SIZE 256      // 256(default) or 128 or 64
//   /*==== use exp() and sin() ====*/
//   #define RGBLIGHT_EFFECT_BREATHE_CENTER 1.85  // 1 to 2.7
//   #define RGBLIGHT_EFFECT_BREATHE_MAX    255   // 0 to 255
// #endif

/* Debounce reduces chatter (unintended double-presses) - set 0 if debouncing is not needed */
#define DEBOUNCE 5

/* define if matrix has ghost (lacks anti-ghosting diodes) */
//#define MATRIX_HAS_GHOST

/* Mechanical locking support. Use KC_LCAP, KC_LNUM or KC_LSCR instead in keymap */
#define LOCKING_SUPPORT_ENABLE
/* Locking resynchronize hack */
#define LOCKING_RESYNC_ENABLE

/* If defined, GRAVE_ESC will always act as ESC when CTRL is held.
 * This is userful for the Windows task manager shortcut (ctrl+shift+esc).
 */
// #define GRAVE_ESC_CTRL_OVERRIDE

/*
 * Force NKRO
 *
 * Force NKRO (nKey Rollover) to be enabled by default, regardless of the saved
 * state in the bootmagic EEPROM settings. (Note that NKRO must be enabled in the
 * makefile for this to work.)
 *
 * If forced on, NKRO can be disabled via magic key (default = LShift+RShift+N)
 * until the next keyboard reset.
 *
 * NKRO may prevent your keystrokes from being detected in the BIOS, but it is
 * fully operational during normal computer usage.
 *
 * For a less heavy-handed approach, enable NKRO via magic key (LShift+RShift+N)
 * or via bootmagic (hold SPACE+N while plugging in the keyboard). Once set by
 * bootmagic, NKRO mode will always be enabled until it is toggled again during a
 * power-up.
 *
 */
#define FORCE_NKRO

/*
 * Magic Key Options
 *
 * Magic keys are hotkey commands that allow control over firmware functions of
 * the keyboard. They are best used in combination with the HID Listen program,
 * found here: https://www.pjrc.com/teensy/hid_listen.html
 *
 * The options below allow the magic key functionality to be changed. This is
 * useful if your keyboard/keypad is missing keys and you want magic key support.
 *
 */

/* key combination for magic key command */
/* defined by default; to change, uncomment and set to the combination you want */
// #define IS_COMMAND() (get_mods() == MOD_MASK_SHIFT)

/* control how magic key switches layers */
//#define MAGIC_KEY_SWITCH_LAYER_WITH_FKEYS  true
//#define MAGIC_KEY_SWITCH_LAYER_WITH_NKEYS  true
//#define MAGIC_KEY_SWITCH_LAYER_WITH_CUSTOM false
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

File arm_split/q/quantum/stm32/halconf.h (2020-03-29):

/*
    ChibiOS - Copyright (C) 2006..2018 Giovanni Di Sirio

    Licensed under the Apache License, Version 2.0 (the "License");
    you may not use this file except in compliance with the License.
    You may obtain a copy of the License at

        http://www.apache.org/licenses/LICENSE-2.0

    Unless required by applicable law or agreed to in writing, software
    distributed under the License is distributed on an "AS IS" BASIS,
    WITHOUT WARRANTIES OR CONDITIONS OF ANY KIND, either express or implied.
    See the License for the specific language governing permissions and
    limitations under the License.
*/

/**
 * @file    templates/halconf.h
 * @brief   HAL configuration header.
 * @details HAL configuration file, this file allows to enable or disable the
 *          various device drivers from your application. You may also use
 *          this file in order to override the device drivers default settings.
 *
 * @addtogroup HAL_CONF
 * @{
 */

#ifndef HALCONF_H
#    define HALCONF_H

#    define _CHIBIOS_HAL_CONF_
#    define _CHIBIOS_HAL_CONF_VER_7_0_

#    include "mcuconf.h"

/**
 * @brief   Enables the PAL subsystem.
 */
#    if !defined(HAL_USE_PAL) || defined(__DOXYGEN__)
#        define HAL_USE_PAL TRUE
#    endif

/**
 * @brief   Enables the ADC subsystem.
 */
#    if !defined(HAL_USE_ADC) || defined(__DOXYGEN__)
#        define HAL_USE_ADC FALSE
#    endif

/**
 * @brief   Enables the CAN subsystem.
 */
#    if !defined(HAL_USE_CAN) || defined(__DOXYGEN__)
#        define HAL_USE_CAN FALSE
#    endif

/**
 * @brief   Enables the cryptographic subsystem.
 */
#    if !defined(HAL_USE_CRY) || defined(__DOXYGEN__)
#        define HAL_USE_CRY FALSE
#    endif

/**
 * @brief   Enables the DAC subsystem.
 */
#    if !defined(HAL_USE_DAC) || defined(__DOXYGEN__)
#        define HAL_USE_DAC TRUE
#    endif

/**
 * @brief   Enables the GPT subsystem.
 */
#    if !defined(HAL_USE_GPT) || defined(__DOXYGEN__)
#        define HAL_USE_GPT TRUE
#    endif

/**
 * @brief   Enables the I2C subsystem.
 */
#    if !defined(HAL_USE_I2C) || defined(__DOXYGEN__)
#        define HAL_USE_I2C TRUE
#    endif

/**
 * @brief   Enables the I2S subsystem.
 */
#    if !defined(HAL_USE_I2S) || defined(__DOXYGEN__)
#        define HAL_USE_I2S FALSE
#    endif

/**
 * @brief   Enables the ICU subsystem.
 */
#    if !defined(HAL_USE_ICU) || defined(__DOXYGEN__)
#        define HAL_USE_ICU FALSE
#    endif

/**
 * @brief   Enables the MAC subsystem.
 */
#    if !defined(HAL_USE_MAC) || defined(__DOXYGEN__)
#        define HAL_USE_MAC FALSE
#    endif

/**
 * @brief   Enables the MMC_SPI subsystem.
 */
#    if !defined(HAL_USE_MMC_SPI) || defined(__DOXYGEN__)
#        define HAL_USE_MMC_SPI FALSE
#    endif

/**
 * @brief   Enables the PWM subsystem.
 */
#    if !defined(HAL_USE_PWM) || defined(__DOXYGEN__)
#        define HAL_USE_PWM TRUE
#    endif

/**
 * @brief   Enables the RTC subsystem.
 */
#    if !defined(HAL_USE_RTC) || defined(__DOXYGEN__)
#        define HAL_USE_RTC FALSE
#    endif

/**
 * @brief   Enables the SDC subsystem.
 */
#    if !defined(HAL_USE_SDC) || defined(__DOXYGEN__)
#        define HAL_USE_SDC FALSE
#    endif

/**
 * @brief   Enables the SERIAL subsystem.
 */
#    if !defined(HAL_USE_SERIAL) || defined(__DOXYGEN__)
#        define HAL_USE_SERIAL FALSE
#    endif

/**
 * @brief   Enables the SERIAL over USB subsystem.
 */
#    if !defined(HAL_USE_SERIAL_USB) || defined(__DOXYGEN__)
#        define HAL_USE_SERIAL_USB TRUE
#    endif

/**
 * @brief   Enables the SIO subsystem.
 */
#    if !defined(HAL_USE_SIO) || defined(__DOXYGEN__)
#        define HAL_USE_SIO FALSE
#    endif

/**
 * @brief   Enables the SPI subsystem.
 */
#    if !defined(HAL_USE_SPI) || defined(__DOXYGEN__)
#        define HAL_USE_SPI FALSE
#    endif

/**
 * @brief   Enables the TRNG subsystem.
 */
#    if !defined(HAL_USE_TRNG) || defined(__DOXYGEN__)
#        define HAL_USE_TRNG FALSE
#    endif

/**
 * @brief   Enables the UART subsystem.
 */
#    if !defined(HAL_USE_UART) || defined(__DOXYGEN__)
#        define HAL_USE_UART FALSE
#    endif

/**
 * @brief   Enables the USB subsystem.
 */
#    if !defined(HAL_USE_USB) || defined(__DOXYGEN__)
#        define HAL_USE_USB TRUE
#    endif

/**
 * @brief   Enables the WDG subsystem.
 */
#    if !defined(HAL_USE_WDG) || defined(__DOXYGEN__)
#        define HAL_USE_WDG FALSE
#    endif

/**
 * @brief   Enables the WSPI subsystem.
 */
#    if !defined(HAL_USE_WSPI) || defined(__DOXYGEN__)
#        define HAL_USE_WSPI FALSE
#    endif

/*===========================================================================*/
/* PAL driver related settings.                                              */
/*===========================================================================*/

/**
 * @brief   Enables synchronous APIs.
 * @note    Disabling this option saves both code and data space.
 */
#    if !defined(PAL_USE_CALLBACKS) || defined(__DOXYGEN__)
#        define PAL_USE_CALLBACKS TRUE
#    endif

/**
 * @brief   Enables synchronous APIs.
 * @note    Disabling this option saves both code and data space.
 */
#    if !defined(PAL_USE_WAIT) || defined(__DOXYGEN__)
#        define PAL_USE_WAIT TRUE
#    endif

/*===========================================================================*/
/* ADC driver related settings.                                              */
/*===========================================================================*/

/**
 * @brief   Enables synchronous APIs.
 * @note    Disabling this option saves both code and data space.
 */
#    if !defined(ADC_USE_WAIT) || defined(__DOXYGEN__)
#        define ADC_USE_WAIT TRUE
#    endif

/**
 * @brief   Enables the @p adcAcquireBus() and @p adcReleaseBus() APIs.
 * @note    Disabling this option saves both code and data space.
 */
#    if !defined(ADC_USE_MUTUAL_EXCLUSION) || defined(__DOXYGEN__)
#        define ADC_USE_MUTUAL_EXCLUSION TRUE
#    endif

/*===========================================================================*/
/* CAN driver related settings.                                              */
/*===========================================================================*/

/**
 * @brief   Sleep mode related APIs inclusion switch.
 */
#    if !defined(CAN_USE_SLEEP_MODE) || defined(__DOXYGEN__)
#        define CAN_USE_SLEEP_MODE TRUE
#    endif

/**
 * @brief   Enforces the driver to use direct callbacks rather than OSAL events.
 */
#    if !defined(CAN_ENFORCE_USE_CALLBACKS) || defined(__DOXYGEN__)
#        define CAN_ENFORCE_USE_CALLBACKS FALSE
#    endif

/*===========================================================================*/
/* CRY driver related settings.                                              */
/*===========================================================================*/
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

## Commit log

2020-02-25 pro microに変更
    [fan-B_Cu.gbr, fan-B_Mask.gbr, fan-B_SilkS.gbr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]
2020-02-26 SN74HC595の両面対応
    [fan-B_Cu.gbr, fan-B_Mask.gbr, fan-B_SilkS.gbr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]
2020-02-26 大幅に手戻り 配線最初から
    [CUI_SJ-43614-SMT-TR.step, HRO TYPE-C-31-M-12.step, PJ-320A.step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]
2020-02-27 再度配線しなおした
    [fan.dsn, fan.kicad_pcb, fan.sch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]
2020-02-27 寸法明記 272.00 x 295.00
    [fan.kicad_pcb]
2020-02-27 アクリルプレート用svgを出力
    [fan.kicad_pcb]
2020-02-27 全体の画像をsvgで出力
2020-02-27 発注した
    [fan.kicad_pcb]
2020-02-28 ケースを別ファイルに分けた
    [fan-Eco1_User.dxf, fan-Eco2_User.dxf, fan.kicad_pcb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]
2020-02-28 アクリルパーツをフットプリントにしている最中 あと一つ大きなフタのみ
    [fan_case-Eco1_User.dxf, fan_case-Eco2_User.dxf, fan_case.kicad_pcb]
2020-02-28 フットプリントを更新
2020-02-29 アクリルレーザーカット用ファイルを追加
    [fan.kicad_pcb, fan_case-Eco1_User.dxf, fan_case-Eco2_User.dxf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]
2020-03-01 アクリルカットサービスに見積もり出した
    [cfan.dsn, fan-Eco1_User.dxf, fan-Eco2_User.dxf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]
2020-03-01 QCADを使うとDXFのレイヤー、線色指定ができた、線幅は0.001にする方法が不明
    [fan_1.25_300x600.dxf]
2020-03-02 印刷用svgを出力してみた
    [fan.kicad_pcb]
2020-03-02 発注したアクリルケースの設計を元の基盤のファイルに含めたので古いファイルを削除
    [noname-Eco1_User.dxf, noname-Eco2_User.dxf, noname.kicad_pcb]
2020-03-04 v2.0 外形考え中
    [fan-Edge_Cuts.dxf, fan-Margin.dxf, fan.kicad_pcb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]
2020-03-04 迷走中...元にもどす
    [fan.kicad_pcb]
2020-03-04 基盤の外形を決定した
    [fan.kicad_pcb, fan.sch]
2020-03-08 v2.0 fan90を受けて修正。これでpro micro用の回路は官僚とする。(ケースはまだない)
    [cfan.dsn, fan-Edge_Cuts.dxf, fan-Margin.dxf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]
2020-03-08 fan74をbluepillに変更
    [fan.kicad_pcb, fan.sch]
2020-03-08 readme.md の修正
2020-03-10 配線にちょっと詰まったのでやり直す
    [fan.kicad_pcb, fan.sch]
2020-03-12 fan74のPCBが一応完成した
    [fan.kicad_pcb, fan.sch, modulo-ergo42-Dwgs_User.dxf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]
2020-03-14 fan74のケースを作成
    [fan.kicad_pcb, fan.sch]
2020-03-14 異種面付けしてみた がしないで3枚注文してもトントンだったので 普通に発注する予定
    [fan.kicad_pcb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]
2020-03-15 天板 底板を作成 したものの、あと数ミリ小さくする予定
    [fan-Eco1_User.dxf, fan-Eco2_User.dxf, fan-Edge_Cuts.dxf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]
2020-03-15 fan90のプログラムを書いてみる前にfan74を保存
    [fan.kicad_pcb]
2020-03-16 JLPCBに注文してみた 安い
    [fan-bottom.GBL, fan-bottom.GBO, fan-bottom.GBS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]
2020-03-25 キーマップを作った うごかない たいへん
2020-03-28 とりあえず使ってないピンを割り当ててピン数をそろえてみた しかし変わらなかった
2020-03-28 PRODUCT_IDを変えてみた 変わらずエラー
2020-03-28 ピン数が合わせられてなかった 1つ足したらうまくいった
2020-03-28 正しく認識されるようにはなった 入力はできない

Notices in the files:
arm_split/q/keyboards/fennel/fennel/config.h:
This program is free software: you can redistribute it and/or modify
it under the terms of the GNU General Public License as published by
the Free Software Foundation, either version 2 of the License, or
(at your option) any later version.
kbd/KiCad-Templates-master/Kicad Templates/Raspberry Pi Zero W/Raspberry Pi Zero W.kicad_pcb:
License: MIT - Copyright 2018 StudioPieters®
